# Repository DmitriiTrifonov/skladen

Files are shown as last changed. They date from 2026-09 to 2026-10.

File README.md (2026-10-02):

<p align="center">
  Mitya Computer logo: a seated shiba in green, its head apart from the body, with a hex nut cut out of it, beside the words Mitya Computer
</p>

<p align="center"><b>English</b> · <a href="README.ru.md">Русский</a></p>

# Mitya Computer Skladen

A clamshell that turns a Pixel 3a XL into a pocketable laptop-shaped terminal.
The name is *skladen* (складень), a hinged Russian travel icon: two panels that
fold shut over what they carry.

This is Mk3, the third iteration, after Mk1 (Blender) and Mk2 (FreeCAD), neither
of them published.

Same phone, new keyboard — a Jomaa KEYBOARD098RU salvaged from its folio case.

<p align="center">
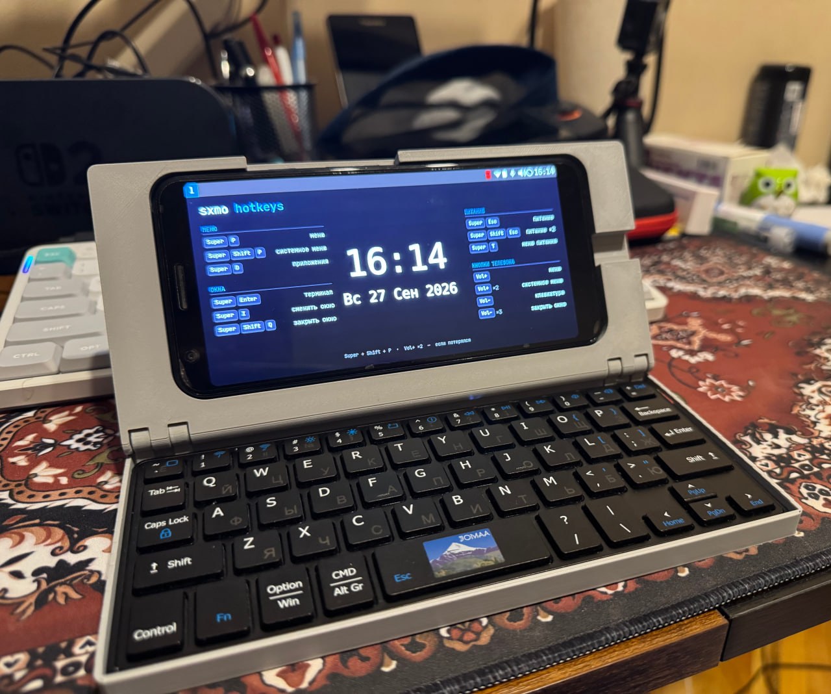
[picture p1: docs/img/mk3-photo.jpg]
The printed Skladen Mk3 open on a desk: grey PETG shell, the phone in the lid showing the Sxmo hotkey screen, the Jomaa keyboard in the base
  
  <br>
  <sub>The first full print, running Sxmo.</sub>
</p>

**The goal of Mk3 is to be as thin as possible.** Mk2 is roughly 32 mm closed;
Mk3's design point is 22.2 mm, with both components fully enclosed and the
keyboard never opened.

<p align="center">
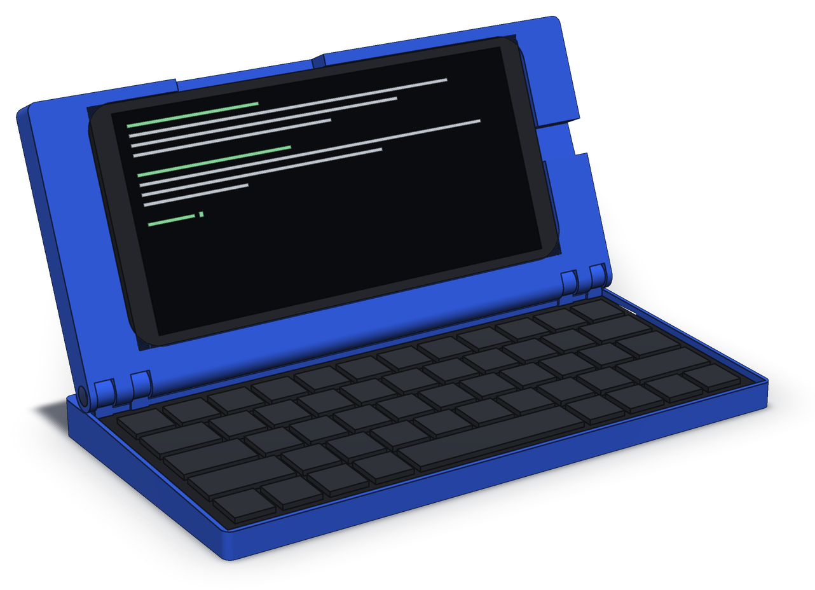
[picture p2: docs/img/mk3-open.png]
Skladen Mk3 rendered open at 112 degrees: the phone in the lid showing a terminal, the keyboard in the base
  
  <br>
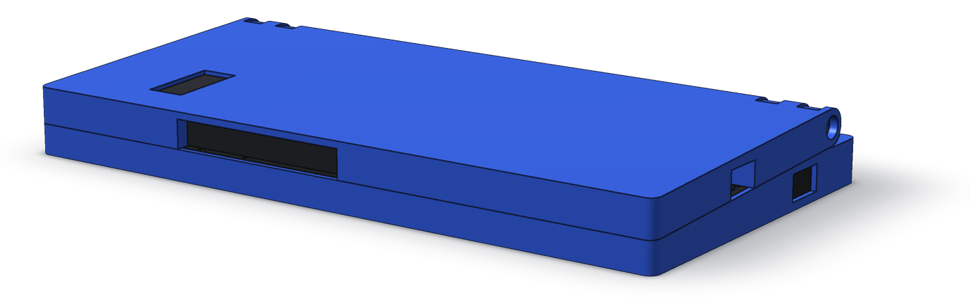
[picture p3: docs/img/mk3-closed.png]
Skladen Mk3 rendered closed, seen from the front right
  
  <br>
  <sub>Shut: 23.24 mm at the hinge, 19.26 at the front. Both renders come straight from the
  model via <code>cad/render.py</code>; the phone and keyboard are stand-ins built from
  their measured envelopes.</sub>
</p>

## Status

Measured, analysed, modelled, and now printing. The geometry is code — `cad/`
builds and self-verifies against the analyses — and the first printed coupons
caught two defects that no check could see, both of which are now checked for:
see [ADR-0010](docs/adr/0010-hinge-station-count.md).

**Design point: 23.24 mm closed at the rear, 19.26 at the front** — the keyboard
is a 2.64 deg wedge, so the closed device is one too. The extra millimetre over
the original 22.24 is tape behind the phone; see
[ADR-0004](docs/adr/0004-phone-retention.md).

| Doc | What it is |
|---|---|
| [requirements.md](docs/requirements.md) | Goals, constraints, acceptance criteria |
| [measurements.md](docs/measurements.md) | Every number, with a confidence tag |
| [analysis/thickness-budget.md](docs/analysis/thickness-budget.md) | Where the closed height goes, and three scenarios |
| [analysis/balance.md](docs/analysis/balance.md) | Whether the heavy lid tips it over, and what it costs to fix |
| [analysis/clamshell-geometry.md](docs/analysis/clamshell-geometry.md) | Why the lid is shallower than the base and the tail stays exposed |
| [plan.md](docs/plan.md) | Phases, critical path, and the five named risks |
| [parameters.md](docs/parameters.md) | Every driving dimension, paired with `cad/params.py` |
| [adr/](docs/adr/README.md) | Ten design decisions: six accepted, one rejected, three open |

## Findings so far

**Neither component gets thinner, so the skins had to go.** The keyboard shell is
9.52 mm and the phone 8.2 mm; together that is 90% of the budget and neither is
negotiable — [ADR-0002](docs/adr/0002-keyboard-integration-depth.md) keeps the
keyboard sealed and defers stripping it to Mk4. What remained were two 1.2 mm
skins: the lid's back and the base's floor. Deleting both is what gets the device
under 20 mm.

**Both skins were spent on enclosure, deliberately.** Neither was structurally
necessary: the keyboard's own bottom shell could have been the base's floor
(-1.2 mm), and the phone's own back could have been the lid's outer face
(-1.2 mm), for a 19.8 mm device with both components exposed.
[ADR-0008](docs/adr/0008-base-floor.md) and
[ADR-0004](docs/adr/0004-phone-retention.md) declined both. The result is 22.24 mm
with everything enclosed — a 30% reduction over Mk2 instead of 38%. That was the
trade, and it leaves only 0.26 mm against the current hard limit, which
[needs restating](docs/requirements.md#n1-needs-restating).

**The hinge is printed, not bought.** Holding the lid takes 0.10-0.12 N*m — the
very bottom of the commercial torque-hinge range, where Reell's scaled-down
consumer-electronics series starts at 0.11 N*m. Printed knuckles on two M3 bolted
stations deliver it at 22-25 N of clamp each, still a light load for an M3. The governing idea is that **the bolt sets deflection and a
compliant washer sets force**, so the setting is adjustable with a screwdriver
and survives PETG creep. Stations rather than a full-width rod, because racking
resistance comes from the span between the outermost points, not from continuity
— and a 193 mm printed barrel would bow. Two stations rather than three because
a bolt can only reach a station from outside the device: the lid's rounded rear
runs the full width along the hinge axis, so a centre station had no way in
([ADR-0010](docs/adr/0010-hinge-station-count.md)). No lead time, which took the longest
item off the critical path. Purchased torque hinges stay recorded as an upgrade
path in [ADR-0005](docs/adr/0005-hinge-mechanism.md).

**The tipping problem turned out to be free to fix.** The phone (167 g) outweighs
the keyboard (95 g) and the device tips past 127 deg of opening unaided. Fixing
it entirely — no tipping at any angle — costs 15 mm of rear setback, which is
zero mass and zero thickness — and the same 15 mm is where the hinge stations
stand. Nothing like the
substantial ballast that Mk2's `palmtop_weighted` name implies.

## Layout

```
docs/          requirements, measurements, analyses, ADRs
docs/img/      README photo, and renders from cad/render.py
cad/           build123d model: params.py drives it, build.py checks and exports
cad/logo/      the logo artwork the lid inlays are cut from
export/device/    STL and STEP for the device: lid + base (DIN 985 nylon nut)
export/plainnut/  base for a plain DIN 934 nut + threadlocker; lid from device/
export/coupon21/  hinge-station coupons; the base's also carries the switch slot
export/switch/    shuttle that works the keyboard's power switch from the rear face,
                  three finger lengths by five stem lengths: print the set, keep what works
export/logo/      Mitya Computer logo: lid-logo (recessed) + the green inlay
                  that fills it, for a two-filament print
export/drawings/  SVG views and sections
```

## Licence

Copyright Dmitrii Trifonov 2026.

The design — the model in `cad/`, the files it exports, and the documentation — is
released under the [CERN Open Hardware Licence Version 2 – Strongly Reciprocal](LICENSE)
(CERN-OHL-S-2.0). Under this licence the Python model is the design's source: if
you adapt it, to a different phone or keyboard say, and distribute the result or
anything built from it, you share your modified source under the same terms.

**Except the Mitya Computer name and logo.** The artwork in `cad/logo/` and
`docs/img/mitya-computer.svg`, and the logo it puts into `export/logo/`, are not
released under that licence: all rights reserved. They are in the repository so the lid can be built with them, not for
reuse. A device you make and distribute from this design should use the plain lid
in `export/device/`, which carries no logo, or one of your own.

Source location: <https://github.com/DmitriiTrifonov/skladen>

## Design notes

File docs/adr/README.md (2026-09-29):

# Architecture decision records

One file per structural decision, written before the geometry is committed to
CAD. See [ADR-0001](0001-record-architecture-decisions.md) for why.

| # | Decision | Status | Blocked on |
|---|---|---|---|
| [0001](0001-record-architecture-decisions.md) | Record design decisions as ADRs | Accepted | — |
| [0002](0002-keyboard-integration-depth.md) | How deeply to integrate the keyboard | **Accepted** — stays sealed, stripping deferred to Mk4 | — |
| [0003](0003-lid-balance-strategy.md) | Keeping the device from tipping backwards | **Accepted** — 15 mm rear setback + empty ballast pocket |
| [0004](0004-phone-retention.md) | How the phone is held in the lid | **Accepted** — closed pocket with a rear wall | — |
| [0005](0005-hinge-mechanism.md) | Hinge mechanism | Proposed | Coupon 2.2 — measured torque of a printed bolted hinge |
| [0006](0006-rear-edge-io-vs-hinge.md) | Keyboard I/O on the hinge edge | **Rejected** — the premise was a misread photograph | — |
| [0007](0007-cad-toolchain.md) | CAD toolchain | **Accepted** — build123d, model is Python in `cad/` |
| [0008](0008-base-floor.md) | Base floor | **Accepted** — full 1.2 mm floor kept; Option E open | Task 0.4 (Option E only) |
| [0009](0009-closure-retention.md) | Keeping the device shut when closed | Proposed | Coupon 2.2 — does hinge torque survive 100 cycles |
| [0010](0010-hinge-station-count.md) | How many hinge stations, and how a bolt reaches its pocket | Proposed — two stations, heads outboard | First article — does the lid sag at mid-span |

## Dependency order

```
0002 (keyboard sealed, ACCEPTED)
   |
   +--> only two 1.2 mm skins left as thickness levers, both now spent:
   |        0008 (base floor, ACCEPTED: kept)
   |        0004 (lid rear wall, ACCEPTED: kept)   --> 22.24 mm
   |            +--> tape behind the phone (0004, 2026-09-29) --> 23.24 mm
   |            |
   |            +--> 0008 Option E (0.8 ribbed floor) is the last 0.4 mm
   |
   +--> 0006 (rear I/O stays a live problem)
            |
   0005 (hinge) <--> 0003 (setback) <--> 0006 (rear I/O)
        all three resolve into one rear-edge cross-section
            |
            +--> 0009 (stays shut) rides on 0005's measured torque

0007 (toolchain) gates everything but depends on nothing
```

## The shape of the design as it stands

0002 fixed the keyboard as an untouchable 9.52 mm block, leaving two 1.2 mm skins
as the only thickness levers. 0008 spent one on an enclosed base; 0004 spent the
other on a protected phone back, the fingerprint reader it covers being unused.

The result is **22.24 mm** — a 30% reduction over Mk2 with both components fully
enclosed, rather than the 38% that was available with both exposed. That was the
trade, made twice and deliberately.

**It left 0.26 mm of margin against N1's hard limit of 22.5, which was not a
margin.** The limit has since been restated to 24.5, and 1.0 of it went to tape
behind the phone (0004), putting the device at **23.24 mm**. Two things follow: 0008 Option E (a 0.8 ribbed floor, stiffer than the
flat 1.2 it replaces) is now the project's only remaining reduction and should be
resolved early; and the hard limit itself needs restating, since 22.5 was derived
from an early estimate of this very scenario.

On balance, the two decisions nearly cancelled: 0008 added 26 g low, 0004 added
25 g high, and the device tips at 127 deg. A **15 mm** rear setback eliminates
tipping at any angle across the whole plausible mass bracket — 11 mm covered only
the expected case — and 0006 uses that tail as a shelf for the keyboard's
rear-edge I/O.

So the three open structural ADRs remain one problem: **the rear-edge
cross-section**, where the hinge, the setback and the keyboard's switch, LEDs and
USB-C all have to share the same 15 mm of depth.

0005 has since made that section easier in two ways. Its printed knuckles on
bolted stations have **no lead time**, so they no longer block the drawing; and
because the stations occupy points rather than the whole rear line, the gaps
between them are free for port tunnels. What is left blocking the cross-section
is a single measurement, task 0.1.

0009 turned out to need no hardware of its own. Holding the lid shut while
inverted takes the same 0.091 N*m as holding it at 90 deg — the moment arm is the
same in both cases — so the hinge torque F3 already demands satisfies F8 with
margin. Magnets stay recorded as insurance, with a note to check the phone's
magnetometer first.

One more consequence surfaced along the way and is written up in
[clamshell-geometry.md](../analysis/clamshell-geometry.md): with an inboard axis,
a lid the same depth as the base **does not open at all** — its rear overhang
drives straight into the setback tail. The lid is therefore 197 x 90 and the base
197 x 105, with the tail exposed even when shut, exactly as a laptop's hinge
region is. Full 0-180 deg remains available.

0010 came out of a question asked while looking at an assembly drawing: would the
bolt actually go in? It would not. The lid's rounded rear is a solid cylinder
coaxial with the hinge, so it blocks the bolt's path equally at every opening
angle, and the centre station had no path at all. Neither the interference check
nor the 0-180 deg sweep could see it — an unassemblable joint overlaps nothing.
The station count dropped to two and `build.py` gained a corridor check, next to
the connectivity check added the same day for the same class of blindness.

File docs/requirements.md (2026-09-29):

# Requirements

## Context

Mitya Computer Skladen Mk3 is the third iteration of a clamshell that turns a
Pixel 3a XL into a pocketable laptop-shaped terminal. Mk1 (`../pixel_palmtop`,
Blender) and Mk2 (`../palmtop_mk2`, FreeCAD) both worked, but Mk2 is bulky: a
170 x 91.4 footprint with a base part 23.35 tall and a lid part 18.21 tall.

Mk3 keeps the same phone and swaps in a much slimmer keyboard (Jomaa
KEYBOARD098RU, salvaged from its folio case).

## Primary goal

**Minimise closed thickness.** Every other property is negotiable against it,
within the constraints below.

## Functional requirements

| # | Requirement |
|---|---|
| F1 | Holds a Pixel 3a XL in landscape orientation in the lid, screen facing the keyboard when closed |
| F2 | Holds the Jomaa keyboard in the base |
| F3 | Opens and stays open, hands-free, at any angle within the supported range |
| F4 | Does not tip over backwards at any supported opening angle, on a desk |
| F5 | Keyboard USB-C reachable without disassembly. The power switch is worked from the base's rear face through a printed shuttle, so a keyboard that glitches can be power-cycled without disassembly (added 2026-09-29; it was first left permanently ON); the status LEDs are not required to be visible |
| F6 | Phone USB-C reachable for charging while the device is open and in use |
| F7 | **Relaxed.** The phone is taped into the lid, as Mk2's was, so it comes out with a pry and some patience rather than in 30 seconds. An accepted trade, not a requirement met — see [ADR-0004](adr/0004-phone-retention.md) |
| F8 | Stays shut when closed, including inverted in a bag — see [ADR-0009](adr/0009-closure-retention.md) |

## Non-functional requirements

| # | Requirement |
|---|---|
| N1 | Closed thickness at the thickest point: target <= 20.0, hard limit <= 24.5. Design point is **23.24** — the target is missed by 3.24 through deliberate trades, [ADR-0008](adr/0008-base-floor.md) and [ADR-0004](adr/0004-phone-retention.md) (the lid's rear skin, and 1.0 of tape behind the phone). Limit restated by the owner, see below |
| N2 | Footprint: base ~197 x 105 including the 15 mm rear setback; lid ~197 x 90, ending at the hinge axis, leaving the tail exposed when closed (see [clamshell geometry](analysis/clamshell-geometry.md)) |
| N3 | Printable on a 256 x 256 bed without the base being split into multiple parts |
| N4 | Total mass <= 400. Currently ~374 as printed (~432 if it were solid) — measure against the slicer's figure, not `volume x density` |
| N5 | No custom electronics — keyboard and phone stay stock |
| N6 | Parametric CAD: all key dimensions driven from one table, so a different phone or keyboard is a re-parametrisation, not a redraw. Satisfied by [ADR-0007](adr/0007-cad-toolchain.md) — `docs/parameters.md` paired with `cad/params.py` |

## Explicit non-goals

- Modifying the phone or flashing anything on it
- Adding a trackpad, extra battery or any powered component
- Water or drop resistance beyond "survives being carried in a bag"

## Acceptance criteria

The build is done when all of the following hold on the physical device:

1. Closed thickness measured at the thickest point is within N1.
2. The open device does not tip backwards when the lid is at the maximum
   supported angle and the screen is tapped firmly at its top edge.
3. The lid holds position at 100, 120 and the maximum supported angle after
   50 open/close cycles.
4. Keyboard can be charged and power-cycled with the device fully assembled.
5. Phone can be charged with the device open and in use.
6. Phone can be removed and reinserted without damaging either the phone or the
   lid. Not quickly — F7 was relaxed when the phone went onto tape.

## N1 needs restating

The hard limit of 22.5 was written before any construction was chosen, as a round
number just above an early estimate of what is now the selected scenario. The
device has landed at 22.24, so the limit constrained with 0.26 mm of margin — and
it is constraining against a number derived from itself.

This matters because the contingency is real: if coupon 2.4 shows the base flexes
under typing, the floor goes from 1.2 to 2.0-2.5 and the device becomes 23.0-23.5.
There is no headroom to absorb that.

Two responses, not exclusive:

1. Pursue [ADR-0008](adr/0008-base-floor.md) Option E — a 0.8 floor ribbed into
   the keyboard's rim recess, which is *stiffer* than the flat 1.2 it replaces
   and gives back 0.4. This is the project's only remaining reduction.
2. Replace 22.5 with a limit that means something — a pocket, a bag sleeve, a
   number the owner actually cares about — rather than one back-derived from a
   spreadsheet.

**Answered 2026-09-29:** the owner accepts "a couple of millimetres" over the
old figure, so the hard limit is now **24.5**. The first 1.0 of that went
straight to tape behind the phone ([ADR-0004](adr/0004-phone-retention.md)),
leaving 1.26 — enough to absorb the thicker-floor contingency above at 2.0,
not at 2.5.

## Scope boundary with Mk4

[ADR-0002](adr/0002-keyboard-integration-depth.md) keeps the keyboard sealed for
Mk3. Stripping it to its bare plate — worth an estimated 16.5-18.5 mm closed, but
irreversible on the only unit in hand — is deferred to Mk4, to be attempted once
a working Mk3 exists as a fallback. Mk3 must therefore leave the keyboard
removable without cutting anything.

## Open decisions

See [the ADR index](adr/README.md). ADR-0002 is settled; the remaining structural
decisions are not. The analyses in `docs/analysis/` exist to inform them.

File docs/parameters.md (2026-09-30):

# Parameters

**Generated from `cad/params.py` — do not edit by hand.**
Regenerate with `.venv/bin/python cad/gen_params_doc.py`.

The Python is the source of truth; this file exists so the numbers are readable
and reviewable in a diff, as [ADR-0007](adr/0007-cad-toolchain.md) requires.

All lengths mm, masses g, angles deg.

Status: `M` measured · `S` from spec · `D` decided in an ADR · `C` calculated
from others here · `A` assumed, not yet verified

---

## Keyboard — Jomaa KEYBOARD098RU

| Name | Value | St | Note |
|---|---|---|---|
| `kbd_span_x` | 194 | M |  |
| `kbd_depth_y` | 86.25 | M |  |
| `kbd_h_rear` | 9.52 | M | thickest, rear of the wedge |
| `kbd_h_front` | 5.54 | M | thinnest, front |
| `kbd_keycap_rear` | 1.82 | M |  |
| `kbd_keycap_front` | 1.82 | M | owner: same as rear |
| `kbd_mass` | 95 | M |  |
| `kbd_rim_width` | 1.68 | M | perimeter rim on the underside |
| `kbd_wedge_angle` | 2.642 | C | atan((h_rear - h_front) / depth) |

## Keyboard USB-C — on the RIGHT SIDE face, not the rear edge

| Name | Value | St | Note |
|---|---|---|---|
| `kbd_usbc_rear_inset` | 8 | M | rear edge to the near end of the connector |
| `kbd_usbc_z_bottom` | 3 | M | opening's lower edge above the rest plane |
| `kbd_usbc_z_top_inset` | 2 | M | opening's upper edge below the top of that face |
| `kbd_usbc_face_h` | 8.9432 | C | the side face is a wedge |
| `kbd_usbc_h` | 3.9432 | C | derived opening height |
| `kbd_usbc_w_ASSUMED` | 9 | A | task 0.1 — the last measurement outstanding |
| `usbc_centre_y` | 75.65 | C | in device coordinates |
| `usbc_centre_z` | 6.1716 | C |  |
| `usbc_cut_w` | 13 | D | opening in the base's right wall, along Y |
| `usbc_cut_h` | 7.5 | D | along Z |

## Keyboard power switch — on the REAR face, under the right station

| Name | Value | St | Note |
|---|---|---|---|
| `kbd_sw_niche_from_right` | 12.5 | M | right side face to the niche's near end; read as 12-13 |
| `kbd_sw_niche_w` | 7.45 | M |  |
| `kbd_sw_niche_h` | 4.1 | M |  |
| `kbd_sw_knob_w` | 4.24 | M |  |
| `kbd_sw_knob_h` | 3.1 | M |  |
| `kbd_sw_knob_end_gap` | 1 | M | knob to the niche's end, at either end of travel |
| `kbd_sw_knob_proud` | 0.75 | M | owner reckons nearer 1.0; checks use 1.0 |
| `kbd_sw_knob_z` | 4.25 | M | centre above the rest plane; the niche's edges say ~5.1 |
| `kbd_sw_travel` | 1.21 | C | ON toward -X, OFF toward +X |
| `sw_knob_x_on` | 80.17 | C | in device coordinates |
| `sw_knob_x_off` | 81.38 | C |  |
| `sw_clr` | 0.2 | D | shuttle sliding fits, per side |
| `sw_prong_t` | 1.2 | D | at the base's slot; thicker on a tighter fork |
| `sw_tip_gap` | 0.05 | D | prong tips to the keyboard's rear face |
| `sw_back_play` | 0.1 | D | head's back face to the slot's end |
| `sw_fork_clr` | 0.1 | D | fork to knob, per side |
| `sw_finger_len` | 0.5, 1, 1.5 | D | fingers into the niche; one print per value |
| `sw_finger_root` | 0.8 | D | at the keyboard's face |
| `sw_finger_tip` | 0.5 | D |  |
| `sw_finger_z0` | 4.7 | D | device Z |
| `sw_finger_z1` | 7.2 | D |  |
| `sw_retract` | 1.8 | C | how far the shuttle pulls back to seat the keyboard |
| `sw_overtravel` | 0.5 | D | per end; absorbs the niche's X reading |
| `sw_head_w` | 7.04 | C | fork, across both prongs |
| `sw_z0` | 3.6 | D | prongs' lower end, device Z |
| `sw_head_z1` | 8.2 | D | prongs' top, under the station posts at 8.54 |
| `sw_stem_w` | 4 | D |  |
| `sw_stem_h` | 3 | D |  |
| `sw_stem_proud` | 0.5, 1, 1.5, 2, 3 | D | stem's end out of the rear face; one print per value |

## Phone — Pixel 3a XL

| Name | Value | St | Note |
|---|---|---|---|
| `phone_x` | 160.1 | S | long axis, horizontal in the lid |
| `phone_y` | 76.1 | S |  |
| `phone_z` | 8.2 | S | body, excluding the camera bump |
| `phone_mass` | 167 | S |  |
| `phone_corner_r_front` | 8.86 | M | plan view, button edge; from Mk2's pocket sketch |
| `phone_corner_r_rear` | 10.4 | M | plan view, hinge edge |
| `phone_front_wall` | 4 | D | biased forward so the buttons are reachable |
| `tape_t` | 1 | D | double-sided tape, on the pocket's FLOOR |
| `pocket_z` | 9.2 | C | phone_z + tape_t |
| `button_win_x0` | -48.6 | M | button window, from Mk2's STL |
| `button_win_x1` | 5 | M |  |
| `cam_x0` | -69.8 | M | camera cutout, from Mk2's STL |
| `cam_x1` | -58.6 | M |  |
| `cam_from_edge0` | 8.85 | C | referenced to the phone's own button-side edge |
| `cam_from_edge1` | 32.05 | C |  |
| `phone_usbc_cut_w` | 12 | D | phone's own port, lid's right wall |
| `phone_usbc_cut_h` | 7 | D |  |

## Materials and clearances

| Name | Value | St | Note |
|---|---|---|---|
| `mat_density` | 0.00127 | S | g/mm3, PETG, SOLID — see the note in params.py |
| `wall_t` | 1.6 | A |  |
| `clr_kbd` | 0.3 | A | per side, depth |
| `clr_kbd_x` | 0.6 | M | per side, span: absorbs measured print shrinkage |
| `clr_phone` | 0.3 | A | per side |
| `keycap_gap` | 0.3 | D | held open by the base's rim, not by a liner |
| `corner_r` | 3 | D | outer vertical corners |

## Base

| Name | Value | St | Note |
|---|---|---|---|
| `base_floor_t` | 1.2 | D | ADR-0008 |
| `base_x` | 198.4 | C | kbd_span_x + 2*(wall_t + clr_kbd_x) |
| `base_depth_to_axis` | 90.05 | C |  |
| `hinge_setback` | 15 | D | ADR-0003 |
| `base_y` | 105.05 | C | base_depth_to_axis + hinge_setback |
| `foot_dia` | 10 | D | locating recesses for bumpons |
| `foot_recess` | 0.4 | D |  |
| `foot_y_rear` | 99.05 | C | sets the tipping contact line — see ADR-0003 |
| `foot_y_front` | 8 | D |  |
| `foot_inset_x` | 12 | D |  |

## Lid

| Name | Value | St | Note |
|---|---|---|---|
| `lid_rear_wall` | 1.2 | D | ADR-0004, closed pocket |
| `lid_x` | 198.4 | C | matches base_x |
| `lid_y` | 90.05 | C | ends at the hinge axis |
| `lid_t` | 10.4 | C | lid_rear_wall + pocket_z |
| `lid_rear_radius` | 5.2 | C | half the lid thickness |

## Logo — the Mitya Computer dog, inlaid in the lid's outer face

| Name | Value | St | Note |
|---|---|---|---|
| `logo_height` | 40 | D | ear tip to paws |
| `logo_depth` | 0.6 | D | half the rear wall; three 0.2 layers |
| `logo_centre_y` | 42.35 | C | centred over the phone |
| `logo_reads_open` | True | D | upright to someone facing the open lid |

## Derived stack

| Name | Value | St | Note |
|---|---|---|---|
| `parting_rear` | 12.54 | C | top of the keycaps |
| `parting_front` | 8.56 | C |  |
| `rim_rear` | 12.84 | C | where the lid lands |
| `rim_front` | 8.86 | C |  |
| `closed_h_rear` | 23.24 | C | **the N1 number** |
| `closed_h_front` | 19.26 | C |  |
| `close_tilt` | 2.5307 | C | the lid shuts nose-down onto the wedge |

## Hinge

| Name | Value | St | Note |
|---|---|---|---|
| `hinge_axis_y` | 90.05 | C |  |
| `hinge_axis_z` | 18.04 | C | lid mid-thickness, NOT the parting plane |
| `hinge_torque_req` | 0.091 | C | N*m at 90 deg |
| `knuckle_od` | 9 | D | capped by the lid's thickness at the axis |
| `knuckle_id` | 3.5 | D | M3 clearance |
| `knuckle_clr` | 0.2 | D | per face |
| `station_outer_w` | 6 | D | each base knuckle |
| `station_inner_w` | 5.8 | D | the lid knuckle |
| `station_w` | 18.2 | C |  |
| `station_relief_r` | 6.2 | C | lid_rear_radius + 1.0, so a post can exist |
| `post_half_y` | 2.5 | D |  |
| `nut_af` | 5.7 | D | M3 nut across flats |
| `nut_depth` | 4.3 | D |  |
| `head_dia` | 5.8 | D |  |
| `head_depth` | 3.8 | D | head plus a wave washer |

## Masses and balance — estimates, risk R3

| Name | Value | St | Note |
|---|---|---|---|
| `infill_chunky` | 0.42 | A | chunky blocks take infill; thin walls print solid |
| `r_lid` | 45 | A | superseded in build.py by a value derived from the geometry |
| `d_base` | 41 | A | keyboard mass is rear-biased |

## Hinge stations

At X = -87.5, 87.5, span 175.0 mm between the outermost.

## Still blocked

| Parameter | Waiting on |
|---|---|
| `kbd_rim_recess` | task 0.4 |
| `phone_camera_bump` | task 0.6 |

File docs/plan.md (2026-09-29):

# Plan

## Where the project stands

Measurements for the keyboard and phone are in hand, two analyses are written,
and the first decision is made.

Five decisions are made, and the model is now code.

**[ADR-0002](adr/0002-keyboard-integration-depth.md): the keyboard stays sealed.**
Stripping it to its plate — worth an estimated 16.5-18.5 mm closed, but
irreversible on the only unit in hand — is deferred to Mk4. That fixed 9.52 mm of
the stack as untouchable and left exactly two 1.2 mm skins as thickness levers.

**[ADR-0008](adr/0008-base-floor.md): the base keeps a full floor**, for
enclosure and stiffness. **[ADR-0004](adr/0004-phone-retention.md): the lid keeps
a rear wall**, for rear protection — the fingerprint reader it covers will not be
used. Both levers spent. Design point:

```
   rear edge   23.24 mm      front edge   19.26 mm   (22.24 / 18.26 before
                                                    floor tape, ADR-0004)
   (Mk2 is roughly 32 mm, to be confirmed with calipers)
```

A 30% reduction over Mk2 with both components fully enclosed, rather than the 38%
that was available with both exposed. That left 0.26 mm against N1's original hard
limit of 22.5; the limit has since been restated to 24.5 and 1.0 of it spent on
tape behind the phone — see
[requirements.md](requirements.md#n1-needs-restating).

On balance the two decisions nearly cancelled — 26 g added low, 25 g added high —
and the device tips at 127 deg. A **15 mm** rear setback eliminates tipping at any
angle across the whole plausible mass bracket, and
[ADR-0006](adr/0006-rear-edge-io-vs-hinge.md) uses that tail as an I/O shelf. See
[balance.md](analysis/balance.md).

Five ADRs remain open. Four are blocked on measurements rather than preference.

## Phase 0 — close the blocking unknowns

Nothing in CAD should start before these exist. Each unblocks a specific ADR.

| # | Task | Unblocks |
|---|---|---|
| 0.1 | ~~USB-C position~~ done — right side face, 8 mm back from the rear edge. Still needed: the port **opening's width**, and the overmould size of the cable actually used | sizes the opening in the base's right wall |
| 0.4 | Measure the bottom-rim recess depth at 6+ points around the perimeter | ADR-0008 Option E — **the only remaining thickness reduction** |
| 0.5 | Measure the physical Mk2's closed height with calipers | benchmark for N1 |
| ~~0.6~~ | Superseded — Mk2's camera cutout measured off its STL and transferred. It is a through-hole, so the bump height never mattered | — |
| 0.7 | Buy M3 x 16 socket caps (DIN 912), M3 nylon-insert nuts (DIN 985 — the pocket is sized for their 4.00 height, and a plain nut would need a threadlocker nobody can re-apply once the lid is in) and a range of compliant elements — 3 x 1 NBR O-rings, TPU washers — so coupon 2.2 tunes torque by swapping rather than reordering. DIN 137B wave washers are 6.0 OD and do not fit the Ø5.80 head pocket | ADR-0005, ADR-0010 |
| ~~0.8~~ | Superseded — the phone is taped in, as Mk2's was, so there are no retention lips to size | — |
| 0.9 | Check the phone's magnetometer against a loose magnet at ~8 mm | ADR-0009 Option B |
| ~~0.10~~ | Superseded — Mk2's button window measured off its STL and transferred; same phone, same orientation, centred in X in both | — |
| 0.11 | Look at how Mk2's lid treats its top edge around the buttons — relieved, or continuous | ADR-0004; confirms Mk2's no-accidental-press evidence transfers |

Task 0.4 is back on the critical path. With both skins spent, scenario A-thin — a
0.8 floor ribbed into the keyboard's rim recess, taking 22.24 to 21.84 — is the
only reduction left in Mk3, and the 0.26 mm of margin against the hard limit
makes it worth having. It is also data Mk4 will want.

Checking whether a spare keyboard is purchasable is off the critical path, but
still worth knowing for Mk4.

**Owner decision needed, not a measurement:** what the real thickness ceiling is.
See [requirements.md](requirements.md#n1-needs-restating).

Hinge sourcing used to be the longest item here. It is gone:
[ADR-0005](adr/0005-hinge-mechanism.md) now recommends printed knuckles on
bolted stations with a compliant element setting the friction force, all of it
stock hardware. Purchased torque hinges remain
a defined upgrade path, with a sourcing spec recorded in that ADR.

## Risks

Named explicitly, because the task table above lists unknowns that are cheap to
close and says nothing about the ones that are not.

### ~~R1 — the rear edge may not have room for both the hinge and the USB-C~~

**Gone.** The USB-C is on the keyboard's right side face, not on the rear edge,
so the hinge has all 193 mm of that edge to itself. The stations are symmetric at
±88 and the span between them is 1.5% short of ideal rather than 10.8%.

The risk was real given what was believed at the time, and it was tracked and
mitigated correctly. It was also founded on a misread photograph — see
[ADR-0006](adr/0006-rear-edge-io-vs-hinge.md), which is kept as the record.

### R2 — no thickness margin at all

22.24 against a 22.5 hard limit. If coupon 2.4 shows the base flexes under
typing, the floor goes to 2.0-2.5 and the device becomes 23.0-23.5. Nothing
absorbs that.

Mitigated by [ADR-0008](adr/0008-base-floor.md) Option E (worth 0.4 and
*stiffer* than the floor it replaces) and by restating N1's ceiling — see
[requirements.md](requirements.md#n1-needs-restating).

### R3 — the balance analysis rests on estimated masses

**Partly realised already.** The first parametric model showed the hand estimates
were roughly half of reality — the lid's 18 mm-wide solid side rings had never
been counted. The masses are now a bracket (lid 40-83 g, base 42-72 g) rather
than a guess, and [ADR-0003](adr/0003-lid-balance-strategy.md) went from 11 mm of
setback to 15 to cover the whole of it.

What remains is that the bracket is itself estimated, and `r_lid` and `d_base`
still are too. The keyboard's internal mass distribution is not modelled at all,
and it is 69% of the base mass.

Mitigated by coupon 2.5 (weigh and re-run `cad/params.py`) and by carrying the
ballast pocket as a correction lever.

### R4 — the Mk2 benchmark was never measured

"Roughly 32 mm" is an estimate from a photograph. Every "-30% vs Mk2" claim in
this repo rests on it. Task 0.5 fixes it for the price of picking up calipers.

### R6 — knuckle print orientation conflicts with printing the base as one part

A 197 x 105 base realistically prints floor-down, which puts the hinge knuckles'
layer lines across the bending load they carry — the weak direction, and the only
direction the lid's weight acts in. [ADR-0005](adr/0005-hinge-mechanism.md)
Option G (separate bolted knuckle blocks) is the way out, at the cost of parts
and of play accumulating across two bolted interfaces.

Mitigated by printing the knuckle section both ways in coupon 2.2 and loading
both to failure.

### R5 — single-point measurements

Keycap protrusion (1.82) and the bottom-rim recess (<1 mm) were each measured at
one point and are used as if uniform. Tasks 0.3 and 0.4.

## Unassigned detail problems

Real work with no owner and no ADR. None blocks the cross-section, but all of
them have to exist before Phase 3.

| Problem | Note |
|---|---|
| Local gussets under the hinge stations | The base's rear pocket wall is 12.54 tall at 1.6 thick and takes point loads ([ADR-0005](adr/0005-hinge-mechanism.md)) |
| Where the opening grip goes | Mk2 had no accidental-press problem with the same layout, so this is a styling choice rather than a fix |
| Felt liner, now optional | No longer sets the keycap gap — the base's rim does. Worth having as screen protection |
| Styling of the exposed tail | [clamshell-geometry.md](analysis/clamshell-geometry.md) makes it an exterior surface; better decided than discovered |

## Phase 1 — decide

Close [ADR-0007](adr/0007-cad-toolchain.md) immediately; it depends on nothing.

Then resolve **0003, 0005 and 0006 as a single rear-edge cross-section drawing**,
not as three separate decisions. They share the same 10 mm of depth and the same
9.5 mm of height: the hinge, the setback tail and the keyboard's switch, LEDs and
USB-C all have to coexist in that section.

[ADR-0004](adr/0004-phone-retention.md) can close in parallel, after coupon 1.3.

## Phase 2 — coupons before the whole thing

Small test prints, each answering one question.

| # | Coupon | Question it answers |
|---|---|---|
| 2.1 | Rear-edge cross-section, 40 mm wide, both halves | Does hinge + setback + I/O access actually fit in the section, and does the lid open? **Do this one first** (R1) |
| 2.2 | Printed two-station knuckle section with M3 bolts and compliant washers | What torque does it actually produce, measured with a spring scale? Is it adjustable by feel? How much is lost over 100 cycles? Does it rack? |
| 2.3 | Lid pocket corner, full thickness | Does the phone seat and stay in? Does the camera cutout clear the bump? Can the phone be pushed back out? |
| 2.4 | Base pocket, full 193 x 86 footprint but short, printed at both 1.2 and 0.8+ribs | Does the keyboard seat and stay in? Does the floor flex under typing? Is the 0.8 ribbed floor sound (scenario A-thin)? |
| 2.5 | Weigh 2.3 and 2.4, extrapolate to full shells | Replaces the `E`-confidence masses in the balance analysis (R3) |

Re-run the balance numbers after 2.5. If they move materially, revisit ADR-0003
before Phase 3 rather than after.

## Phase 3 — v1

Full base and lid, assembled with the real keyboard and phone. Expect this to be
wrong in at least two places; the point is to find out which two.

## Phase 4 — validate

Against the acceptance criteria in [requirements.md](requirements.md). The ones
that will actually bite:

- Closed thickness against whatever N1's restated ceiling turns out to be
- Tip test at maximum opening angle with a firm tap on the top of the screen
- 50 open/close cycles, then re-check that the lid still holds 120 deg
- Keyboard removable without cutting anything — Mk4 depends on it
- Phone temperature under sustained use, with its back fully enclosed

## Phase 5 — publish

Mk2 was published on MakerWorld (`../palmtop_mk2/maker_world/`). Same for Mk3:
STL + STEP + photos, and a link back to this repo for the reasoning.

## Critical path

```
0.1 I/O positions    --> ADR-0006 --+--> 2.1 rear cross-section --> Phase 3
                         ADR-0003 --+
                         ADR-0005 --+ (2.2 validates, does not block)
0.4 rim recess depth --> ADR-0008 opt E --> 2.4 base floor --> Phase 3
```

**Nothing on this path has a lead time any more.** Task 0.1 is now the only thing
blocking the rear-edge cross-section, and it is a caliper and ten minutes. Task
0.4 is the same, and it gates the only millimetres left in the budget. Both
should happen next.

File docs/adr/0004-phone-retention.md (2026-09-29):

# ADR-0004: How the phone is held in the lid

- **Status:** Accepted
- **Date:** 2026-09-20
- **Decides:** F1, F6, F7; contributes 1.2-1.5 mm to N1 and ~25 g to the
  [balance problem](../analysis/balance.md)

## Context

The lid is ~197 x 90; the phone is 160.1 x 76.1 x 8.2 and sits in it in
landscape, leaving ~18 mm of margin on each side and ~7 mm front and rear.

The phone's camera bump takes the envelope to 9.4 mm over part of the rear face.
Its fingerprint reader is on the rear, upper third — reachable only if the rear
is open. Its USB-C is on a short edge, which in landscape points sideways, so
charging access (F6) is easy in every option here.

This decision is doubly weighted: the lid skin is 1.2 mm of the closed stack
*and* ~25 g of lid mass, and lid mass is the thing that tips the device over. The
lighter option is also the thinner option and the more stable one.

## Options

### Option A — closed pocket (chosen)

A tray with a full rear wall; the phone drops in and is captured by a lip on the
front face. Cutouts for the camera, fingerprint reader and USB-C.

| Pros | Cons |
|---|---|
| Phone's rear is fully protected | +1.2 mm closed height, +25 g lid mass |
| Stiffest lid for the least material, no rib scheme needed | Fingerprint reader is covered — decisive, and the reason this option was previously discounted |
| Cleanest exterior | Heat from the phone has nowhere to go |
| Simple to model and print flat | Tool-free removal needs a deliberate push-out feature |
| Camera bump passes through a cutout; the wall does not thicken | |

### Option B — open bezel frame

A perimeter frame with lips that grip the phone's front face; the phone's own
rear is the outer surface of the closed device.

| Pros | Cons |
|---|---|
| Thinnest and lightest: 0 mm of skin, ~15 g | Zero rear protection — the phone's glass back faces the world |
| Camera bump protrudes into free air, needs no pocket | Frame must grip the front bezel, which intrudes on screen edges |
| Fingerprint reader and rear fully accessible | Least stiff; a 197 x 90 open frame in PETG will flex |
| Best case in the balance analysis | Phone retention relies entirely on lip engagement and friction |
| Phone dissipates heat normally | |

### Option C — frame plus removable rear cover

Model B, and additionally a snap-on rear panel that can be fitted or left off.

| Pros | Cons |
|---|---|
| The user picks thin-and-exposed or thick-and-protected, per outing | Two parts to design, two to keep aligned, one to lose |
| The frame can be stiffened by the cover when fitted | The frame must be stiff enough to work *without* the cover anyway, so the weight saving is smaller than in B |
| Good fallback if B turns out too flexible | Most CAD work of the three |

### Option D — frame with a skeletal rear brace

A frame as in B, plus a diagonal or X-shaped rib across the rear that stiffens
the lid without closing it, routed to clear the camera bump and the fingerprint
reader.

| Pros | Cons |
|---|---|
| Recovers most of B's lost stiffness for ~5 g and 0 mm of added stack (the rib sits over the phone's rear, outside the closed stack) | Rib is the outermost surface and takes every scratch |
| Keeps the fingerprint reader usable | Looks deliberate or looks unfinished, depending on execution |
| Gives somewhere to mount the hinge leaves properly | Needs care to avoid pressing on the camera bump |

## Decision

**Option A — closed pocket with a full rear wall.**

The fingerprint reader is the main function a closed back gives up, and it will
not be used. With that objection removed, the remaining trade is 1.2 mm against
full rear protection for the phone, a stiff lid that needs no rib scheme, and a
clean exterior — and the owner's call is that the protection is worth it.

Closed height becomes **22.24 mm** at the rear, 18.26 at the front.

Note this is 0.40 better than the 22.44 quoted while this ADR was open: that
figure carried a 0.50 air gap between keycaps and screen, which was an artifact
of how the scenario was first written. A closed-back lid takes the same 0.30
felt liner as an open frame — there is no reason for the gap to differ.

## Consequences

### Thickness

- **Every thickness lever in the project is now spent.** 22.24 mm is the design
  point and there is no remaining way to reduce it without reopening
  [ADR-0002](0002-keyboard-integration-depth.md) or
  [ADR-0008](0008-base-floor.md).
- The one refinement still available is ADR-0008 Option E — a 0.8 ribbed floor
  sitting in the keyboard's rim recess — which would give **21.84 mm**. It is
  now worth pursuing rather than optional, because of the margin problem below.
- **N1's hard limit of 22.5 is now binding, with 0.26 mm of margin.** The
  sensitivity note in the [thickness budget](../analysis/thickness-budget.md)
  says that if coupon 2.4 shows the base flexes under typing, the floor goes to
  2.0-2.5 — which would put the device at 23.0-23.5 and break the limit. There
  is no headroom left to absorb that. The limit itself should be restated with a
  real rationale, since 22.5 was derived from an early estimate of this very
  scenario and is self-referential.

### Balance

- The lid gains ~25 g, so `M_lid` goes from 182 to 207 and the bare device tips
  at 127 deg rather than 133.
- That, compounded by the shell masses turning out roughly double the original
  estimates, is what drove [ADR-0003](0003-lid-balance-strategy.md) to a **15 mm**
  rear setback rather than 11. See [balance.md](../analysis/balance.md).
- A design rule follows for this part specifically: **hollow the lid wherever it
  carries no load.** The 18 mm-wide solid rings down each side are dead mass in
  the worst possible place, and removing them moves the balance directly.

### Phone orientation — determined, not chosen

Screen rotation is a software matter. The hardware constraint is that the **power
and volume buttons must end up on the top edge and stay reachable**, which fixes
the orientation rather than leaving it open.

On the Pixel 3a XL, power and volume are both on the right-hand edge in portrait.
Rotating the phone 90 deg counter-clockwise to bring that edge upward puts:

| Phone edge | Lands on | Needs |
|---|---|---|
| Right — power, volume | Lid's top long edge, away from the hinge | Cutouts or relief |
| Bottom — USB-C | Lid's **right** short edge | Cutout, required by F6 |
| Top — 3.5 mm jack | Lid's left short edge | **Nothing — no cutout.** Decided; the jack is not used |
| Left — SIM tray | Lid's bottom long edge, at the hinge | Nothing; inaccessible and unimportant |

This is the same orientation Mk2 used, which is visible in
`../palmtop_mk2/maker_world/palmtop.jpg` — the earpiece and front camera sit on
the left of the landscape screen, meaning the portrait top points left.

**Accidental button presses: not a problem in practice.** The lid's top edge is
both where the buttons are and where a hand grips to open the clamshell, which
looks like it should cause trouble. Mk2 used the same phone in the same
orientation and did not, over its whole service life. That is field evidence from
the predecessor and it outranks reasoning from the geometry.

One difference is worth a glance before assuming it transfers: Mk2's lid was an
open frame, and in `../palmtop_mk2/maker_world/full_opened.jpg` its top edge
appears to be relieved in the middle, with printed material only at the corners.
Mk3's closed pocket will have a continuous wall along that edge instead. If that
relief is *why* fingers stayed off the buttons, the change matters; if the reason
is simply that the grip naturally falls on the base, it does not. Worth thirty
seconds with the physical Mk2 rather than a guess from a photograph.

Pressing the buttons themselves is not a tipping concern: the force is directed
down the lid toward the hinge, not perpendicular to the screen. Tapping the
*screen* is the tipping case, and it is already in the acceptance criteria.

### Where the phone sits in the lid, and the button window

The phone is **biased forward**, not centred: 4.00 mm of wall on the button edge,
9.35 mm on the hinge side. Centred would put 6.68 mm in front of the buttons,
which is not an opening but a shaft — a phone case manages with about 1.5.

Mk2 solved this the same way, and its STL was measured rather than guessed:
4.70 front, 9.60 rear, with **one 54.0 x 10.0 window spanning both buttons**
instead of two holes. Mk3 uses 4.00 rather than 4.70 because Mk2's full-width
hinge barrel needed no station reliefs and Mk3's stations do — the bias buys the
material between the phone pocket and the relief, which went from 0.97 mm to
3.65 mm.

Both lids centre the same phone in X in the same orientation, so Mk2's window
span transfers directly: **X -48.6 to +5.0**. Task 0.10 is superseded.

The bias costs balance: it moves `r_lid` from 45.03 to 47.05 and the tipping
margin at 180 deg from 1.225 to about 1.17. The lightening work that N4 requires
anyway more than repays it, but the two must be done in that order.

### The phone is taped in, not gripped

Mk2 held its phone with double-sided tape and no retention lips at all, and that
carries over. The pocket is therefore a plain recess the depth of the phone, with
nothing overlapping the screen — which is what this model already had, so no
geometry changed and **task 0.8 (front bezel width) is superseded**.

**The tape goes on the pocket's floor, and the pocket is 1.0 deeper for it.**
This was first decided the other way: side walls, to keep the closed stack at
22.24 under N1's then hard limit of 22.5. On the side walls it cost only pocket
width — 160.7 to 162.7, side blocks 18.05 to 17.05 — and that widening is kept.

It did not survive assembly (2026-09-29). The first full build went together
with 1 mm tape on the floor, the phone stood 1 mm proud of the lid's face, and
with only `keycap_gap` (0.3) to the keycaps it landed on the keys. Because the
lid pivots about the hinge, the contact nearest the axis governs, and the lid
stood ~4 mm open at its front edge — roughly the whole close tilt.

The owner chose the height over the side-wall discipline: the pocket is now
`phone_z + tape_t` deep, the lid 10.40 thick, and the device closes at
**23.24**. N1's hard limit was restated to 24.5 to match
([requirements](../requirements.md)). Floor tape also means the phone seats
against a flat plane rather than being wedged between walls, which is how it
naturally went together.

Adhesion is nowhere near the constraint. Holding an inverted phone is 1.64 N
against roughly 1250 mm2 of contact on the two short ends alone, and the pocket
already captures the phone on all four sides — the tape only has to stop it
falling out.

### Detail design

- The camera cutout is a **through-hole in the rear wall**, 11.2 x 23.2, again
  taken from Mk2's STL and referenced to the phone's edges. Because it goes
  through, the bump's height never mattered and task 0.6 is superseded — a bump
  taller than the 1.2 wall simply protrudes, as it does on the naked phone.
- A USB-C cutout on the short edge is still required by F6.
- The phone's rear is fully covered, so it sheds heat only through the screen.
  The Pixel 3a XL is not a hot device, but sustained use in a sealed pocket is
  worth watching during Phase 4.
- **Unlocking is PIN or password only.** Recorded as an accepted consequence, not
  an objection — it follows directly from the reason this option was chosen.
- **F7 has been relaxed rather than met.** With the phone taped in, removal means
  prying, not a thumb push. Mk2 lived with this for its whole service life, so it
  is an accepted trade — but it is a trade, and it should not be rediscovered as
  a defect two iterations from now.
- The 53.6 mm button window gives somewhere to get a tool in when the phone does
  have to come out.

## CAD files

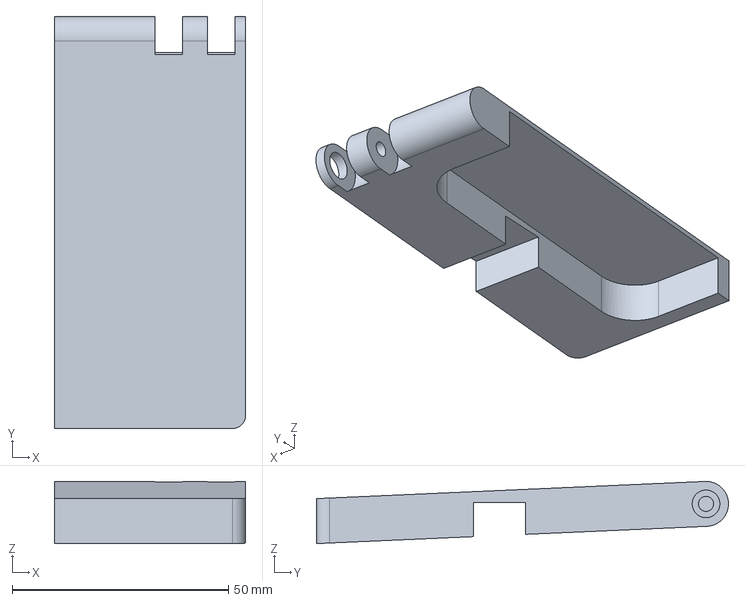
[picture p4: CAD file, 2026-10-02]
export/coupon21/mk3-coupon21-lid.step
44.2 x 95.2 x 14.4 mm

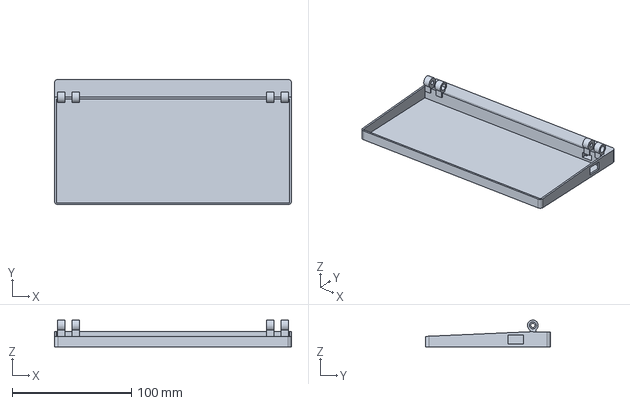
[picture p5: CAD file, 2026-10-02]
export/device/mk3-base.step
198.4 x 105.0 x 22.5 mm

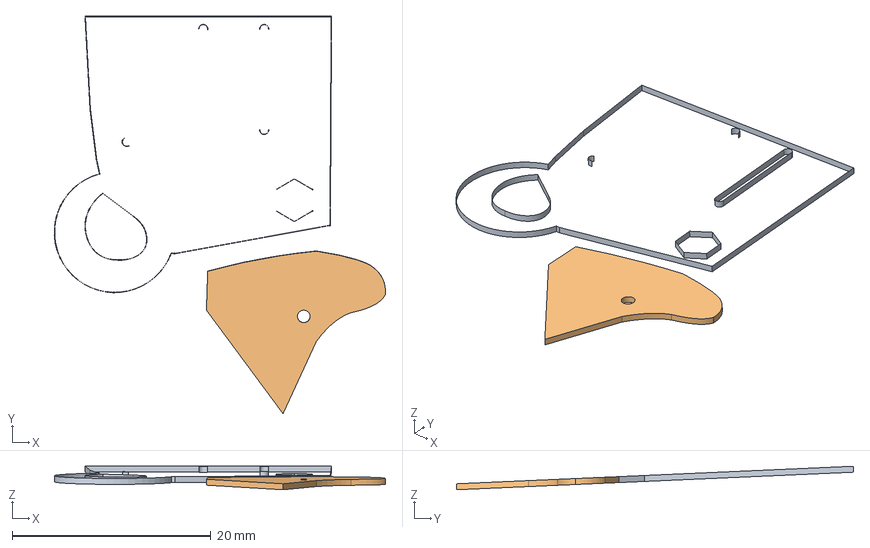
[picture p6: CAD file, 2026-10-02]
export/logo/mk3-logo-green.step
33.3 x 40.0 x 2.37 mm

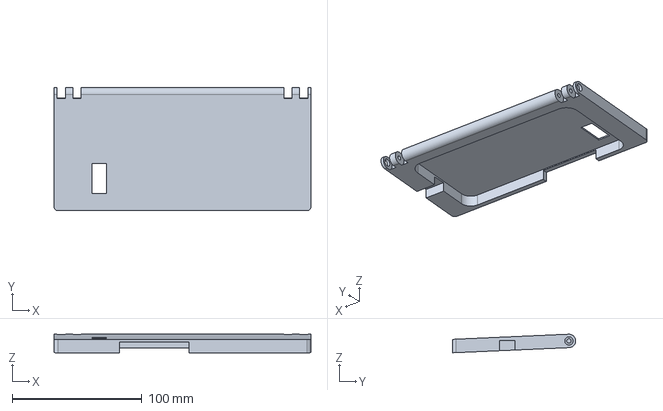
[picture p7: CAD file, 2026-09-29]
export/mk3-lid.step
198.4 x 95.2 x 14.4 mm

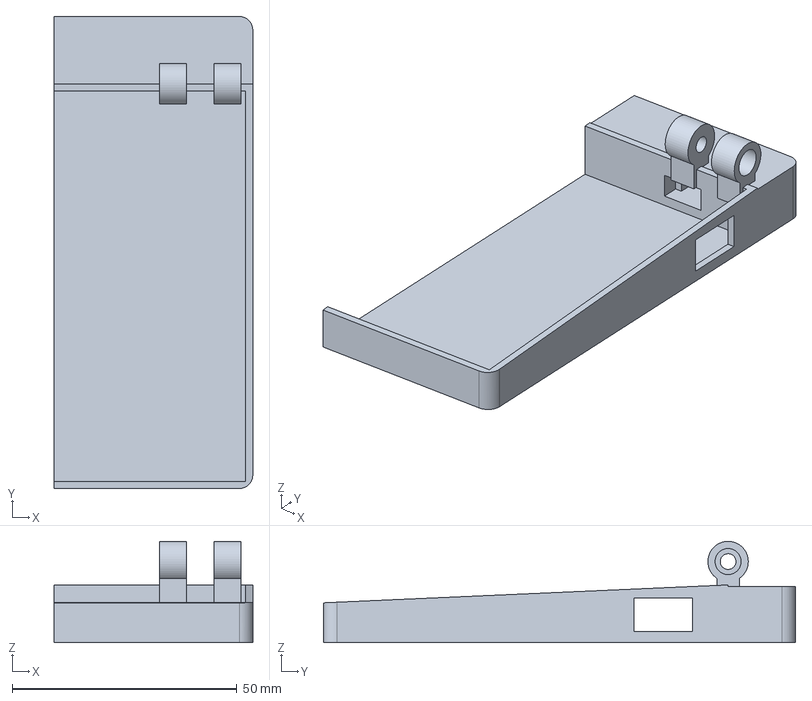
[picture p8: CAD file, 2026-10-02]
export/plainnut/mk3-coupon21-base-plainnut.step
44.2 x 105.0 x 22.5 mm

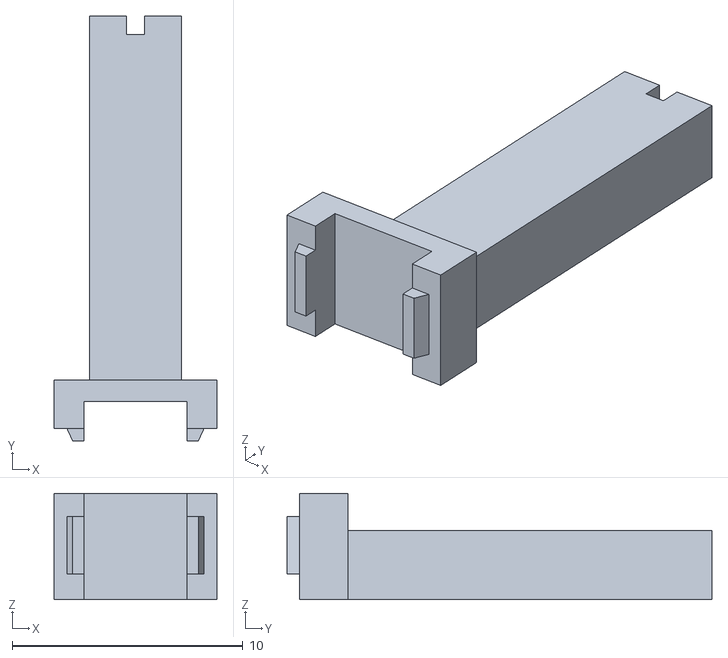
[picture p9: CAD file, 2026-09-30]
export/switch/finger0.5/mk3-switch-shuttle-finger0.5-proud1.0.stl
7.04 x 18.4 x 4.60

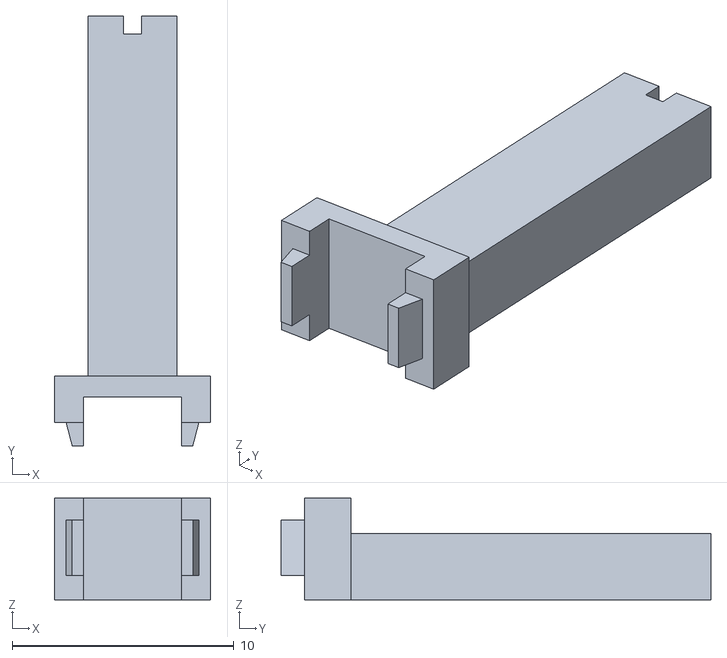
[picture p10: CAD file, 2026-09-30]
export/switch/finger1.0/mk3-switch-shuttle-finger1.0-proud1.5.stl
7.04 x 19.4 x 4.60

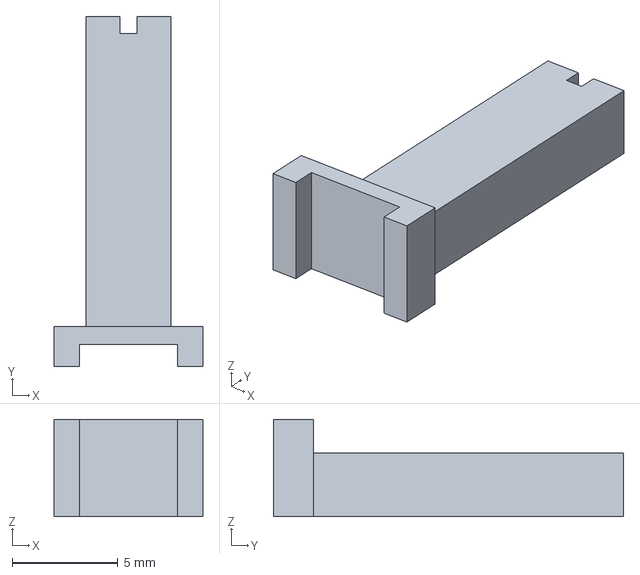
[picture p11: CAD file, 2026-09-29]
export/switch/mk3-switch-shuttle.step
7.04 x 16.5 x 4.60 mm

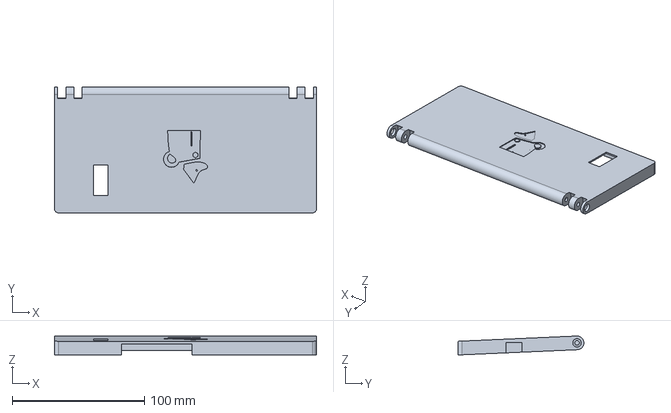
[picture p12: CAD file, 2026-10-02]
export/logo/mk3-lid-logo.step
198.4 x 95.2 x 14.4 mm

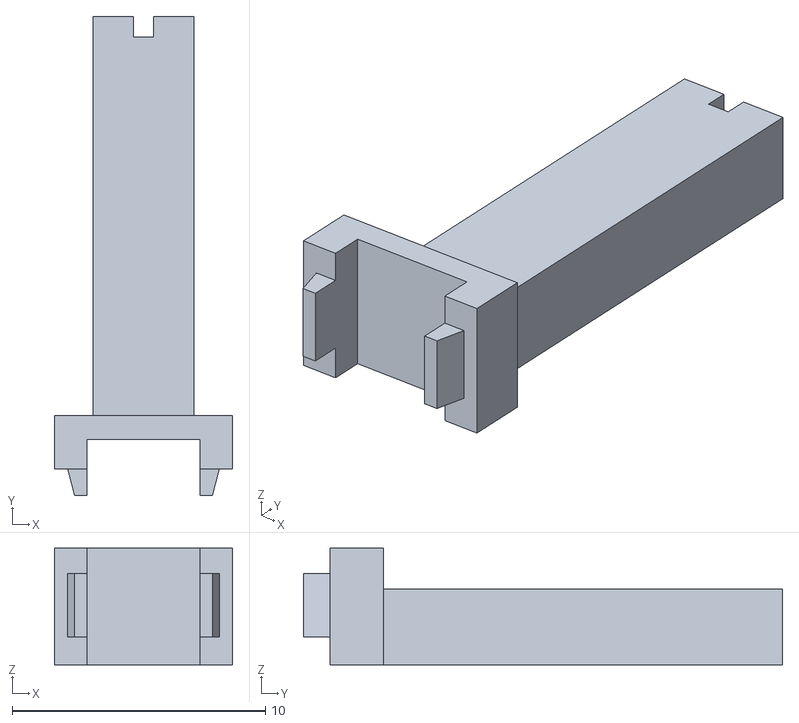
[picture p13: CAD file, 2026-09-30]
export/switch/finger1.0/mk3-switch-shuttle-finger1.0-proud1.0.stl
7.04 x 18.9 x 4.60

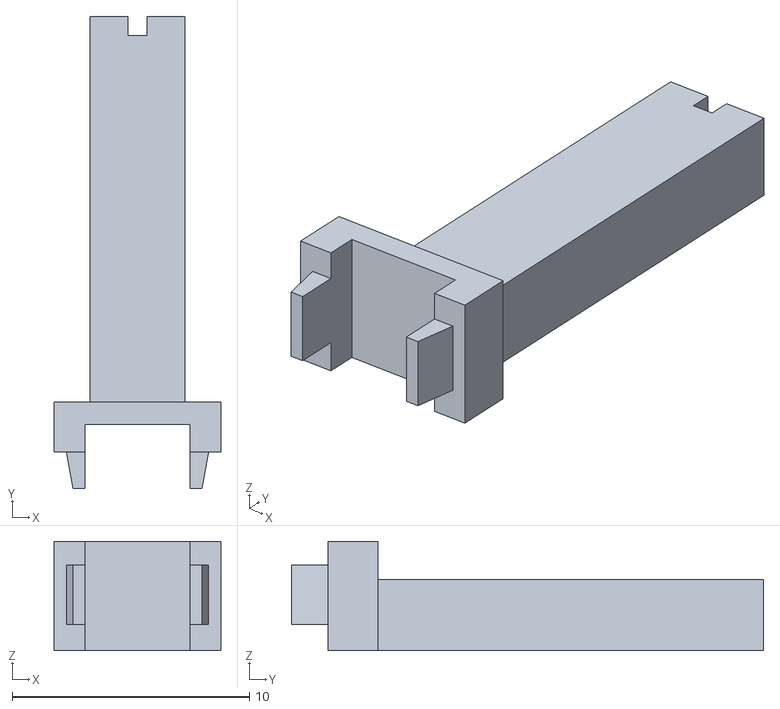
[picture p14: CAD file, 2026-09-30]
export/switch/finger1.5/mk3-switch-shuttle-finger1.5-proud1.5.stl
7.04 x 19.9 x 4.60

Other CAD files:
export/switch/finger1.5/mk3-switch-shuttle-finger1.5-proud1.0.stl
export/coupon21/mk3-coupon21-base.step
export/device/mk3-lid.step
export/mk3-coupon21-lid.step
export/plainnut/mk3-base-plainnut.step
export/switch/finger0.5/mk3-switch-shuttle-finger0.5-proud2.0.stl
export/mk3-coupon21-base-plainnut.step
export/coupon21/mk3-coupon21-base.stl
export/coupon21/mk3-coupon21-lid.stl
export/device/mk3-base.stl
export/device/mk3-lid.stl
export/logo/mk3-lid-logo.stl
export/logo/mk3-logo-green.stl
export/mk3-base-plainnut.step
export/mk3-base.step
export/mk3-coupon21-base.step
export/plainnut/mk3-base-plainnut.stl
export/plainnut/mk3-coupon21-base-plainnut.stl
export/switch/finger0.5/mk3-switch-shuttle-finger0.5-proud0.5.stl
export/switch/finger0.5/mk3-switch-shuttle-finger0.5-proud1.5.stl
export/switch/finger0.5/mk3-switch-shuttle-finger0.5-proud3.0.stl
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

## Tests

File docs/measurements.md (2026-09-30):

# Measurements

All dimensions in mm, masses in g. Axis convention used throughout the project:

- **X** — span, left-to-right along the key rows (the long axis)
- **Y** — depth, front-to-back (user's body towards the hinge)
- **Z** — height, table to top of the closed device

Confidence tags: `M` measured with calipers, `S` from spec sheet / open sources,
`E` estimated or derived, `?` unknown, must be captured.

## Keyboard — Jomaa KEYBOARD098RU "Ardor Plum"

Bluetooth keyboard, Russian layout, salvaged from its folio case (case discarded).

| Property | Value | Conf |
|---|---|---|
| Span (X) | 194.00 (first reading 193.00; re-measured when it would not go into a printed pocket) | M |
| Depth (Y) | 86.25 | M |
| Height, shell only, rear edge (thickest) | 9.52 | M |
| Height, shell only, front edge (thinnest) | 5.54 | M |
| Height incl. keycaps, rear edge | 11.34 | M |
| Keycap protrusion above shell, rear | 1.82 (design value 2.0) | M |
| Keycap protrusion above shell, front | 1.82 | M | owner: same as rear |
| Mass | 95 | M |
| Bottom face | flat, with a perimeter rim 1.68 wide and < 1.0 tall | M |
| Top face | wedge, rises front → rear | M |
| Wedge angle (derived) | atan((9.52-5.54)/86.25) = 2.64 deg | E |

### I/O

The rear (thick) edge carries the OFF/ON slide switch and the four status LEDs —
see `reference/photos/keyboard-rear-edge-switch-leds.jpg`.

**The USB-C port is on the keyboard's RIGHT SIDE face**, not on the rear edge.
`reference/photos/keyboard-rear-edge-usb-c.jpg` shows that face, and an earlier
reading of it as the rear edge seen at an angle was wrong. That misreading
invented the hinge-versus-I/O conflict that
[ADR-0006](adr/0006-rear-edge-io-vs-hinge.md) existed to solve.

> `reference/` is gitignored — the photos and borrowed models in it are local
> only and do not travel with a clone. Every dimension they support is recorded
> in this file; the images are corroboration, not the source of record.

Datums: distance measured **back from the keyboard's rear (high) edge** along the
right side face; Z from the plane the keyboard rests on.

| Feature | Value | Conf |
|---|---|---|
| USB-C, rear edge to the near end of the connector | 8.00 | M |
| USB-C opening, lower edge above the rest plane | 3.00 | M |
| USB-C opening, upper edge below the top of that face | 2.00 | M |
| Side face height at the port (derived, the face is a wedge) | 8.94 | C |
| USB-C opening height (derived) | 3.94 | C |
| USB-C opening width, along the keyboard's depth | assumed 9.0 | ? - confirmed by fit |
| OFF/ON slide switch | rear edge, niche 12.5 from the right side face — see below | M |
| LEDs x4 | rear edge, not needed | D |

In device coordinates the opening centres on **Y 75.65, Z 6.17**, in the base's
right wall.

Two things worth a second look: the assumed 9.0 opening width, and whether the
3 and 2 were taken to the visible opening or to the connector housing.

The switch was first left permanently ON and the LEDs are not required to be visible, so
**USB-C was the only feature on this edge needing access** — see
[ADR-0006](adr/0006-rear-edge-io-vs-hinge.md) and F5.

**Height matters as much as X.** The hinge axis sits at 12.54 above the desk and
the keyboard's rear face tops out at 10.72, so a port mounted high on that face
cannot share an X position with a hinge station — see R1 in
[plan.md](plan.md). Tasks 0.1 and 0.1b.

**Task 0.1 is closed by fit, not by callipers (2026-09-22).** The first printed
coupon's window lines up with the real keyboard's port, so the assumed 9.0 never
has to become a measurement. The tolerance was worked out beforehand and is
recorded next to the parameter: the opening spans 6.0 to 19.0 back from the
keyboard's rear edge, against a measured 8.00 where the connector starts, so any
true width up to 11.0 is cleared with 2.0 to spare at the rear end. A USB-C
receptacle is 8.34.

This edge is also the natural hinge edge, which is a direct conflict — see
[ADR-0006](adr/0006-rear-edge-io-vs-hinge.md).

### Power switch (measured 2026-09-29)

A glitching keyboard wanted power-cycling, so the switch is now reached after
all — by a shuttle through the base's tail, worked from its rear face. It sits
in a niche right under the right-hand hinge station. ON is toward the
keyboard's left, OFF toward its right.

| Feature | Value | Conf |
|---|---|---|
| Niche, right side face to its near end | 12-13, taken as 12.5 | M |
| Niche, width x height | 7.45 x 4.10 | M |
| Knob, width x height | 4.24 x 3.10 | M |
| Knob, shape | rounded, ellipsoidal — the same size throughout | M |
| Niche, shape | narrows toward its bottom | M |
| Knob to the niche's end, at either end of travel | 1.00 | M |
| Knob travel (derived) | 1.21 | C |
| Knob, proud of the rear face | 0.75, nearer 1.0 by feel | M |
| Knob centre above the rest plane | 4.25 | M |
| Niche edges, above the rest plane / below the top | 3.24 / 2.60 | M |

The two Z readings disagree by about a millimetre: the niche's edges put its
centre near 5.1, against 4.25 read at the knob. The shuttle's prongs span 2.4
to 7.0 above the rest plane, so `build.py` checks that they drive the knob at
both, and the question does not have to be settled before printing.

The knob being rounded is why the first shuttle slipped off it: a flat prong
meets a curved flank, and pushing sideways drives the fork back off the face.
The fork only holds while something keeps it against the face, which the base's
slot does and a hand does not.

### Not yet known (requires teardown)

| Property | Conf |
|---|---|
| Thickness of the keyboard's own bottom shell | ? |
| Thickness of plate + PCB + scissor stack (flat portion) | ? |
| Battery size and location | ? |
| Whether the wedge is pure shell or follows internal parts | ? |

These gate [ADR-0002](adr/0002-keyboard-integration-depth.md).

## Phone — Google Pixel 3a XL

| Property | Value | Conf |
|---|---|---|
| Body | 160.1 x 76.1 x 8.2 | S |
| Envelope incl. camera bump (from Mk2 STL) | 160.1 x 77.1 x 9.4 | E |
| Mass | 167 | S |
| Screen | 6.0" 18:9, used in landscape | S |
| USB-C | bottom edge (short edge) | S |
| Fingerprint reader | rear face, upper third | S |
| Power + volume buttons | right edge in portrait; top long edge of the lid once mounted | S |
| 3.5 mm jack | top edge in portrait; left short edge of the lid — no cutout, unused | S |
| SIM tray | left edge in portrait; hinge-side edge of the lid | S |
| Button positions along the edge, and protrusion | — | ? |
| USB-C position on the short edge | assumed centred | A |
| Front bezel width | not needed | D | no retention lips; the phone is taped in |
| Camera bump height | — | ? | not needed: the cutout is a through-hole |

Orientation is fixed by the requirement that power and volume stay reachable —
see [ADR-0004](adr/0004-phone-retention.md). Edge assignments above assume it.

A reusable solid model exists: `../palmtop_mk2/Pixel_3A_XL_Body.stl`.

## Mk2 reference (the device being replaced)

| Property | Value | Conf |
|---|---|---|
| Footprint | 170.0 x 91.4 | M (from STL) |
| Lid phone pocket | Y -38.55 .. +38.55 | M (from STL) |
| Lid wall, button edge | **4.70** | M (from STL) |
| Lid wall, hinge edge | **9.60** | M (from STL) |
| Button window | **54.0 x 10.0**, at X -48.6 .. +5.0 | M (from STL) |
| Camera cutout | 11.2 x 23.2, at X -69.8 .. -58.6, Y -29.2 .. -6.0 | M (from STL) |

Both the button window and the camera cutout transfer to Mk3 by referencing them
to the **phone's own edges** rather than the lid's, since the two lids differ in
depth and in how the phone sits in them. X transfers unchanged, both lids
centring the same phone on X = 0.

**Mk2 biased the phone forward in the lid** — a thin wall where the buttons are,
a thick one on the hinge side — and cut **one window over both buttons** rather
than two holes. Mk3 does the same. Since both lids centre the same phone in X in
the same orientation, Mk2's window span transfers directly and task 0.10 stops
being a blocker.
| Base part height | 23.35 | M (from STL) |
| Lid part height | 18.21 | M (from STL) |
| Closed height, assembled | ~32 | ? |

The two printed parts interleave at the hinge, so the closed height is less than
the sum. **Action: measure the physical Mk2 with calipers** — this is the number
Mk3 is benchmarked against.

## Print material

| Property | Value | Conf |
|---|---|---|
| Material | PETG (as Mk2) | E |
| Density | 1.27 g/cm3 | S |

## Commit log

2026-09-27 Round the phone pocket's corners in plan, as Mk2's were
    Mk2's pocket sketch rounds its corners at 9.36 (button edge) and 10.90
    (hinge edge) around a 0.5 gap; the phone STL's outline agrees. Mk3 takes
    the phone's own radii from that, 8.86 and 10.40, and adds clr_phone.
    The pocket keeps Mk3's size, 162.7 x 76.7: the long-axis tape gap only
    widens toward the ends, so it never goes negative round a corner. The
    button window, USB-C slot and camera cutout all sit on straight walls.
    [mk3-base-plainnut.step, mk3-base.step, mk3-coupon21-base-plainnut.step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]
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2026-09-29 Deepen the phone pocket for tape behind the phone
    The first full build went together with 1 mm tape on the pocket floor, not
    the side walls. The phone stood 1 mm proud, landed on the keycaps across a
    0.3 gap, and held the lid ~4 mm open at the front edge.
    The owner took the height: the pocket is now phone_z + tape_t deep, the lid
    10.40 thick, and the device closes at 23.24. N1's hard limit is restated to
    24.5. The raised hinge axis made the base's knuckle posts clip the lid's
    underside, so the station relief is now tied to the lid's rear radius
    rather than fixed at 5.70. Both parts need reprinting.
    [mk3-base-plainnut.step, mk3-base-plainnut.stl, mk3-base.step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]
2026-09-29 Sort exports into folders by what gets printed together
    device/ holds the lid and the DIN 985 base, plainnut/ the DIN 934 base
    variant, coupon21/ the hinge coupons, drawings/ the SVG views and sections.
    The drawings are regenerated here: they still showed the 9.40 lid.
    [mk3-base-plainnut.step, mk3-base-plainnut.stl, mk3-base.step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]
2026-09-29 Inlay the Mitya Computer logo in the lid's outer face
    cad/logo.py reads the logo's SVG, thickens its strokes (tail, collar, legs),
    clips the collar to the dog as the artwork does, and cuts one flat region per
    colour. export/logo/ holds the lid with a 0.6 mm recess and a black, teal and
    white inlay that fill it flush, for a multi-material print; the lid alone
    carries the logo as an engraving. The logo is 80 mm across, centred over the
    phone, and reads upright to someone facing the open lid, as Apple's does.
    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
    [mk3-lid-logo.step, mk3-lid-logo.stl, mk3-logo-black.step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]
2026-09-29 Add an engraved logo lid for single-filament prints
    Engraving the whole inlay recess merges the collar, nut, eye and legs into
    one plain silhouette. mk3-lid-logo-engraved cuts only the black, so those
    details stay at the surface and read inside the engraving. build.py checks
    it is one solid and that the cut equals the black inlay's volume.
    [mk3-lid-logo-engraved.step, mk3-lid-logo-engraved.stl]
2026-09-29 Name the device Mitya Computer Skladen
    The README leads with the new name and says where it comes from: a skladen
    is a hinged Russian travel icon, two panels folding shut over what they
    carry. Mk3 stays as the iteration number, so the Mk1/Mk2 history and the
    mk3-* file names still read. The model and parameter docstrings and the
    requirements' opening line follow; paths to the Mk1/Mk2 folders keep
    their old names, since those are the folders' names.
2026-09-29 Inlay only the dog: the lettering broke the logo meshes
    The "a" in "Mitya" came from a variable instance of IBM Plex Sans, whose
    outline crosses itself where the bowl meets the stem. OCCT marks that face
    invalid and cannot mesh it, so every STL cut from the logo had a hole in it:
    OrcaSlicer counted 3175 non-manifold edges on the engraved lid. The lid now
    carries the dog alone, sized by height: 40 mm, ear tip to paws, which leaves
    the leg lines 0.85 wide.
    Two guards so this cannot reach a slicer again. logo.py refuses artwork with
    an invalid shape, and build.py counts the open edges of every STL it writes,
    the device and coupon parts included, and fails the build on any.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
    [mk3-lid-logo-engraved.step, mk3-lid-logo-engraved.stl, mk3-lid-logo.step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]
2026-09-29 Work the keyboard's power switch from the rear face
    The keyboard glitched and wanted power-cycling, which F5 had ruled out by
    leaving the switch permanently ON behind a sealed wall. A printed shuttle now
    reaches it: a fork straddles the knob in a slot through the rear wall, and a
    stem runs back through the tail, under the right station's posts, to a
    fingernail groove in a window in the base's rear face. The switch keeps its
    own detent, so there is no spring and no stop; 0.5 of overtravel each end
    absorbs the niche's position, read only as 12-13 mm from the right.
    The knob's height was read two ways a millimetre apart, so the prongs are
    tall enough for both, and build.py checks the shuttle d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
    [mk3-base-plainnut.step, mk3-base-plainnut.stl, mk3-base.step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]
2026-09-30 Stand the switch shuttle's stem out of the rear face
    Printed, the stem's end sat 0.2 short of the rear face and sank into its
    tunnel with nothing for a fingernail to push against. It now stands proud,
    and build.py exports one shuttle per stem length (0.5 to 3.0) to print as
    a set and choose from. The base is unchanged, so an already printed base
    takes any of them. A new check sweeps the lid 0-180 deg past the longest.
    [mk3-switch-shuttle-proud0.5.step, mk3-switch-shuttle-proud0.5.stl, mk3-switch-shuttle-proud1.0.step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]
2026-09-30 Carry the switch shuttle's prongs into the niche
    The knob is rounded and stands only 0.75 proud, so flat prongs cammed off
    it. Tapered fingers now carry the prongs on into the niche beside the knob,
    in three lengths since the niche's depth is unmeasured, and the shuttle is
    tightened to the keyboard's face. The fingers stand where the keyboard drops
    in, so the base's slot runs 1.8 further back: pull the shuttle back, seat
    the keyboard, push it home. build.py checks the fingers clear the niche at
    both of its height readings and clear the keyboard when pulled back.
    The earlier shuttles do not fit this and are removed.
    [mk3-base-plainnut.step, mk3-base-plainnut.stl, mk3-base.step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]
2026-09-30 Sort the switch shuttles by finger length, STL only
    Fifteen shuttles in one folder, each with a STEP beside it, was hard to
    pick from. They go into a folder per finger length, and as STL alone:
    they are printed, never edited, and the model is their source.
    [mk3-switch-shuttle-finger0.5-proud0.5.step, mk3-switch-shuttle-finger0.5-proud0.5.stl, mk3-switch-shuttle-finger0.5-proud1.0.step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]
2026-10-02 Redraw the lid logo as the green traced dog
    One green inlay with the eye, nut and leg lines as holes, traced from a
    printed test inlay. Drops the per-colour inlays and the engraved lid, and
    puts the new dog in the README lockup.
    [mk3-base-plainnut.step, mk3-base.step, mk3-coupon21-base-plainnut.step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]
2026-10-06 Skladen 2: re-parametrise Mk3 for the Pocophone F1
    Keyboard, base, hinge and power-switch shuttle are unchanged. The lid now
    follows the Pocophone F1 (155.5 x 75.3 x 8.8, 182 g), with dimensions, button
    window and camera cutout read from refs/fun.fbx, and gains a slot in its left
    end for the phone's 3.5 mm headphone jack.
    Closed height is 23.84 mm at the rear (Mk3: 23.24). N4 mass budget raised from
    400 to 420 g. build.py checks plug paths out of the jack and USB-C. See
    docs/adr/0011-phone-swap-pocophone-f1.md.
2026-10-06 Use the measured phone thickness, 9.25 mm
    The owner's caliper reads 9.25 on the flat body and 9.72 over the camera
    block (0.47 proud). The pocket was 8.8 from the spec; the FBX reads 7.9.
    Closed height is now 24.29 mm at the rear, 0.21 under the 24.5 limit. Printed
    mass estimate is ~403 g against the 420 g budget, and the tipping margin at
    180 deg is 1.002.
2026-10-06 Raise the N1 hard limit to 25.0 mm
    The Pocophone's measured 9.25 mm body leaves 0.21 mm under Mk3's 24.5 limit.
    The owner raised the limit to 25.0, leaving 0.71 mm.
2026-10-06 Add a phone-fit coupon: the lid's left end
    Carries the headphone-jack slot, camera cutout, button window and a pocket
    corner, so the real Pocophone can be tried before the whole lid is printed.
2026-10-06 Recompute the hinge holding torque for the heavier lid
    0.118 N*m at 90 deg (Mk3: 0.091): lid and phone ~0.249 kg at 48.1 mm. The
    Mk3 coupon results were for the lower figure, so the hinge coupon has to be
    re-measured. Recorded in ADR-0011.
2026-10-06 Say the Mk3 hinge was tightened by feel, not measured
2026-10-18 Model the clip-on front bezel and its lid as a separate export
    Widen the phone USB-C slot to 9.0 mm. New export/bezel/: lid without tape,
    hollowed ends, ten snap clips, full-front frame, logo lid, and a two-colour
    Bambu project refilled from cad/templates/ with the inlay placed exactly.
    Checks cover interference, closed height and tipping with slicer masses.
    Rebuilt exports and docs/parameters.md follow.
2026-10-18 Document the front bezel, tipping numbers and deferred remedies
    ADR-0012 (as modelled, slicer masses, two-colour print notes), plan tasks
    and risks, deferred steel strip and lid lightening, README rows.
2026-10-18 README: Skladen 2.0.0 is printed; add its photo and the version map
    v1.0.0 is Skladen 1 / Mk3, v2.0.0 the tape-held Skladen 2, 2.1 the clip-on
    bezel. The numbers below the status are still the model's.
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2026-10-19 Weld the vertices in the slicer meshes
    The raw tessellation repeats vertices on shared face edges, which the slicer reads as
    3068 non-manifold edges on the inlay. Weld them, and fail the build on any open edge.
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2026-10-19 Bezel: cover the phone's top bezel down to the picture (8.84 mm), shorter notch tab
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2026-10-23 Crush ribs and button tongues in the bezel lid; closed frame; lid variants on plates 5-8
    Crush ribs on the pocket walls (ADR-0015) take up the phone's side play; the
    first print at 0.40 left it loose, so rib heights 0.50/0.60/0.70 are exported.
    Three flexure tongues in the front wall replace the open button window
    (ADR-0016); a frame closed over the buttons goes with them. Whole-lid variants
    (ribs x tongues) are plates 6-8 of the 2.1 plates project, the closed frame is
    plate 5, and the through-logo lid stays plate 4. Phone-fit coupons for the same
    variants. The USB-C extender seat (ADR-0013) is parked: its build step is off.
    README in every export folder.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
